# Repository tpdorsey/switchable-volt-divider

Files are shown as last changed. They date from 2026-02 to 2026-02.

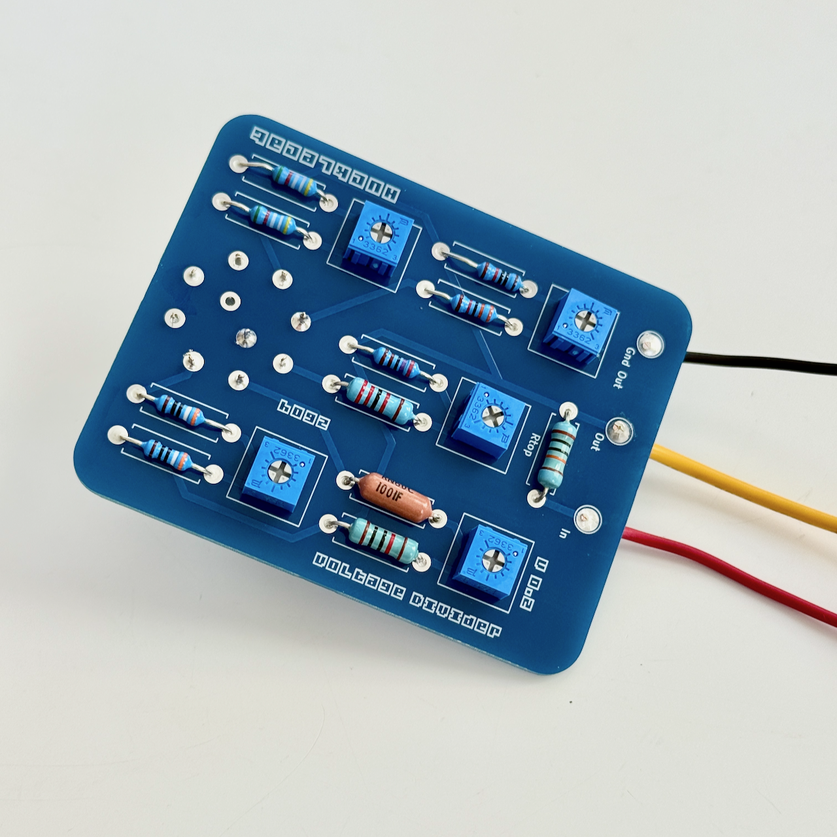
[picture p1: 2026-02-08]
docs/front.png

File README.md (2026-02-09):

# Switchable Voltage Divider PCB — Circuit Overview and Build Guide

This PCB implements a **switchable resistive voltage divider** intended to derive accurate, repeatable fractions of a stable DC reference (nominally 10 V). Each divider tap produces a fixed ratio of the input voltage, selectable via a 1-pole, 5-position rotary switch. 

The design is optimized for trimming resistance values to achieve (relatively) precise divider values.

![Hand-assembled blue PCB voltage divider board with five selectable divider networks. The board shows multiple precision metal film resistors, blue Bourns 3362 trim potentiometers, and a single film capacitor, arranged around labeled divider sections. Three wires exit the right side for input, output, and ground. The layout is clean and symmetric, intended for a switchable precision voltage divider.](docs/front.png)

## Circuit Description

There are five taps on the PCB. Each tap on the PCB has space for two resistors and a trim pot (Bourns 3362).

Each tap is a **two-resistance voltage divider**:

```
Vin ── Rtop ──┬── Vout
              |
            Rbottom
              |
             GND
```

**Rtop** is a fixed value for all taps. (I used 100k.)

**Rbottom** is implemented as:

* A fixed resistor
* A small trim potentiometer (Bourns 3362)
* Optional second series resistor or jumper

This arrangement allows:

* Coarse ratio setting with fixed resistors
* Fine trimming with a low-value trimmer
* Good long-term stability by minimizing the trimmer’s contribution to total resistance

The rotary switch selects which divider output is routed to the output jack.

### Divider Equation

The fundamental voltage divider relationship is:

```
Vout = Vin * (Rbottom / (Rtop + Rbottom))
```

To design a divider for a desired ratio:

```
k = Vout / Vin
```

Solve for the shunt resistor:

```
Rbottom = (k / (1 - k)) * Rtop
```

### Example Divider Values 

Exact values matter. Let's say Rtop = 100,468 Ω.

| Divider ratio | Vout (from 10V) | Rbottom (ideal) |
| ---- | --- | --- |
| 0.5 | 5.0 V | 100,468 Ω |
| 0.3 | 3.0 V | 43,058 Ω |
| 0.2 | 2.0 V | 25,120 Ω |
| 0.1 | 1.0 V | 11,163 Ω |
| 0.01 | 0.1 V | 1,015 Ω |

In practice, these are realized using nearby standard values plus the trim pot to dial in the exact ratio.

You can, of course, use whatever ratios you like.

## Build Notes

The PCB is designed around a 1-pole 5-position (using 1P/8-pos form factor) like the one available from pedal parts supplier [Love My Switches](https://lovemyswitches.com/mini-rotary-switch-1p5t-1-pole-5-position-knurled-shaft/) or [PedalPCB](https://www.pedalpcb.com/product/mini-rotary-switch-1p5t/).

The PCB is also designed to fit within a standard 125B aluminum enclosure with room to install your choice of inputs and outputs (banana jacks, RCA, etc.).

## Build Instructions (Summary)

1. **Populate fixed resistors first**

   * Use precision metal film resistors where possible.
   * Keep resistor types consistent across all taps to improve ratio tempco matching.

2. **Install the trimmer (Bourns 3362)**

   * Use the trimmer only for fine adjustment.
   * Aim to keep it near mid-range once trimmed.

3. **Install jumpers or series resistors**

   * If a second resistor footprint is unused, install a jumper.
   * Otherwise, use it to reduce the trim range and improve stability.

4. **Clean the PCB**

   * Thoroughly remove flux residue, especially around the 0.01 tap.
   * Leakage dominates errors at low-voltage, high-impedance nodes.

5. **Trim each divider**

   * Apply a stable input voltage.
   * Measure Vin and Vout with the same DMM.
   * Adjust the trimmer until the ratio (Vout / Vin) matches the target value.

6. **Final assembly**

   * Mount the PCB and switch in a metal enclosure.
   * Keep wiring short and thermally uniform.

### Notes on Use

* Divider accuracy should be evaluated **ratiometrically**, not as an absolute voltage.
* The 0.01 tap is most sensitive to leakage, temperature gradients, and contamination.
* A metal enclosure significantly improves short-term stability and repeatability.

This design is intentionally simple, adjustable, and reproducible.

## License

<a href="https://github.com/tpdorsey/switchable-volt-divider">Switchable Voltage Divider PCB</a> © 2026 by <a href="https://tpdorsey.com/">Terrence Dorsey</a> <p>is licensed under <a href="https://creativecommons.org/licenses/by-sa/4.0/">Creative Commons Attribution-ShareAlike 4.0 International</a><p>

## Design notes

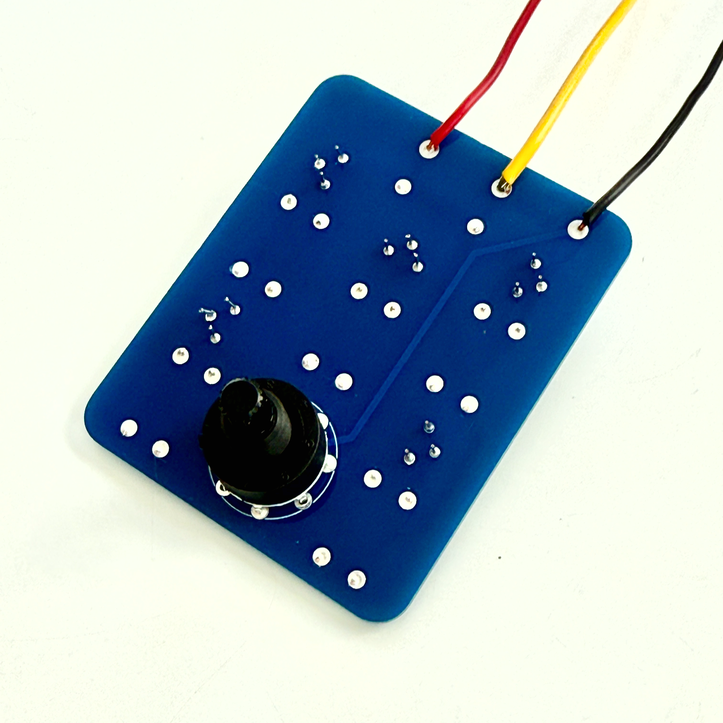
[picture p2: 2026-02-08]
docs/back.png

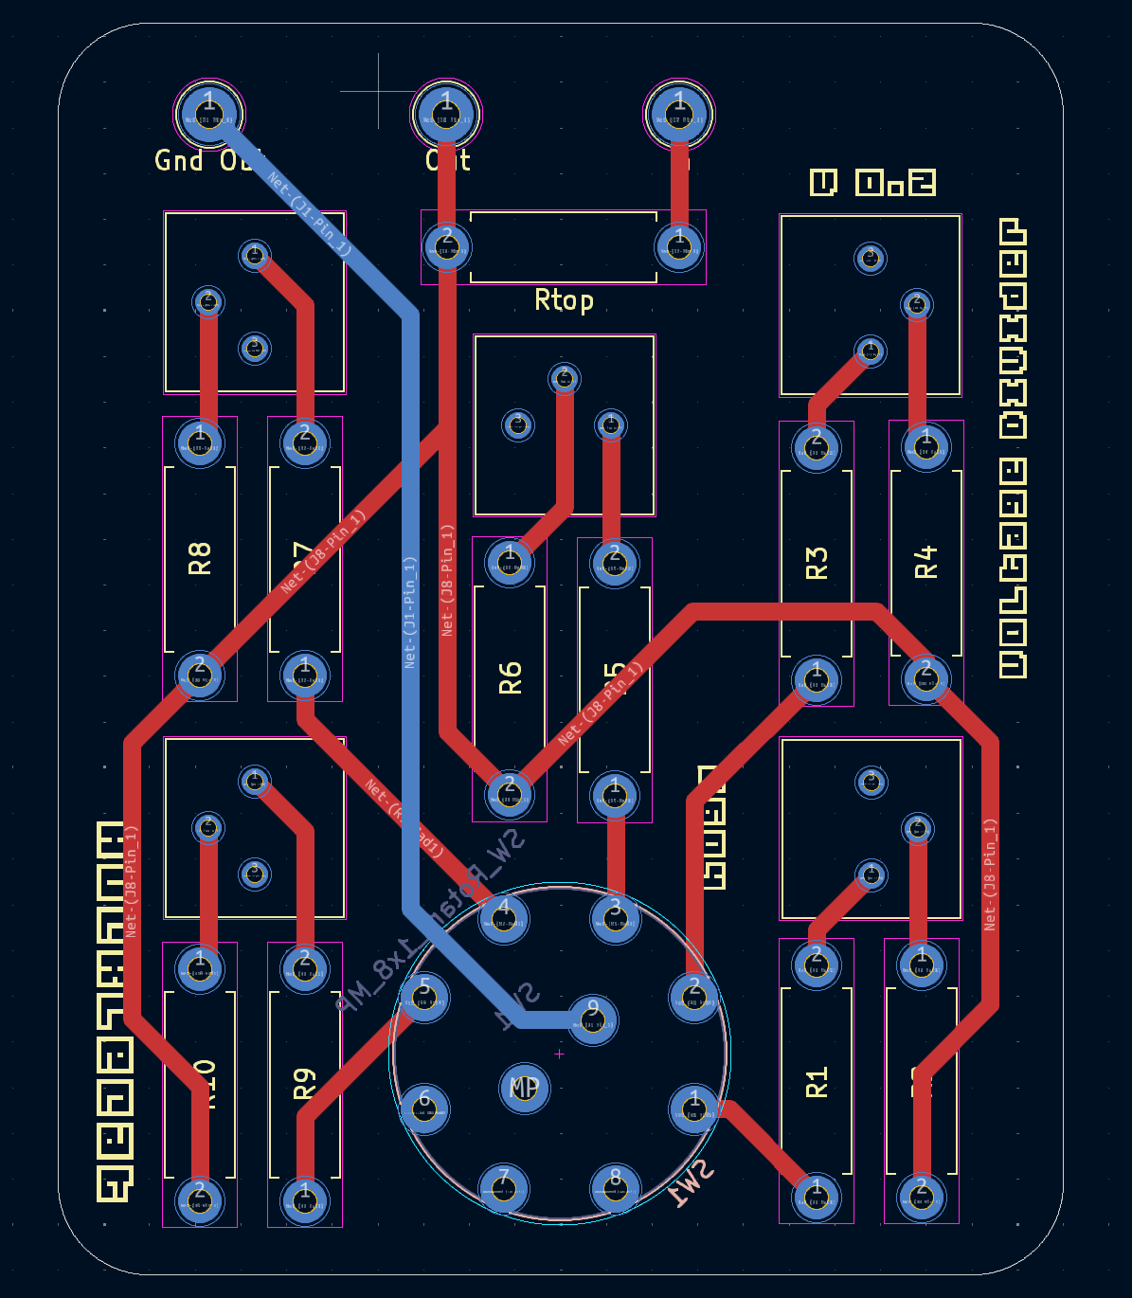
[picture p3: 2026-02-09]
docs/pcb.png

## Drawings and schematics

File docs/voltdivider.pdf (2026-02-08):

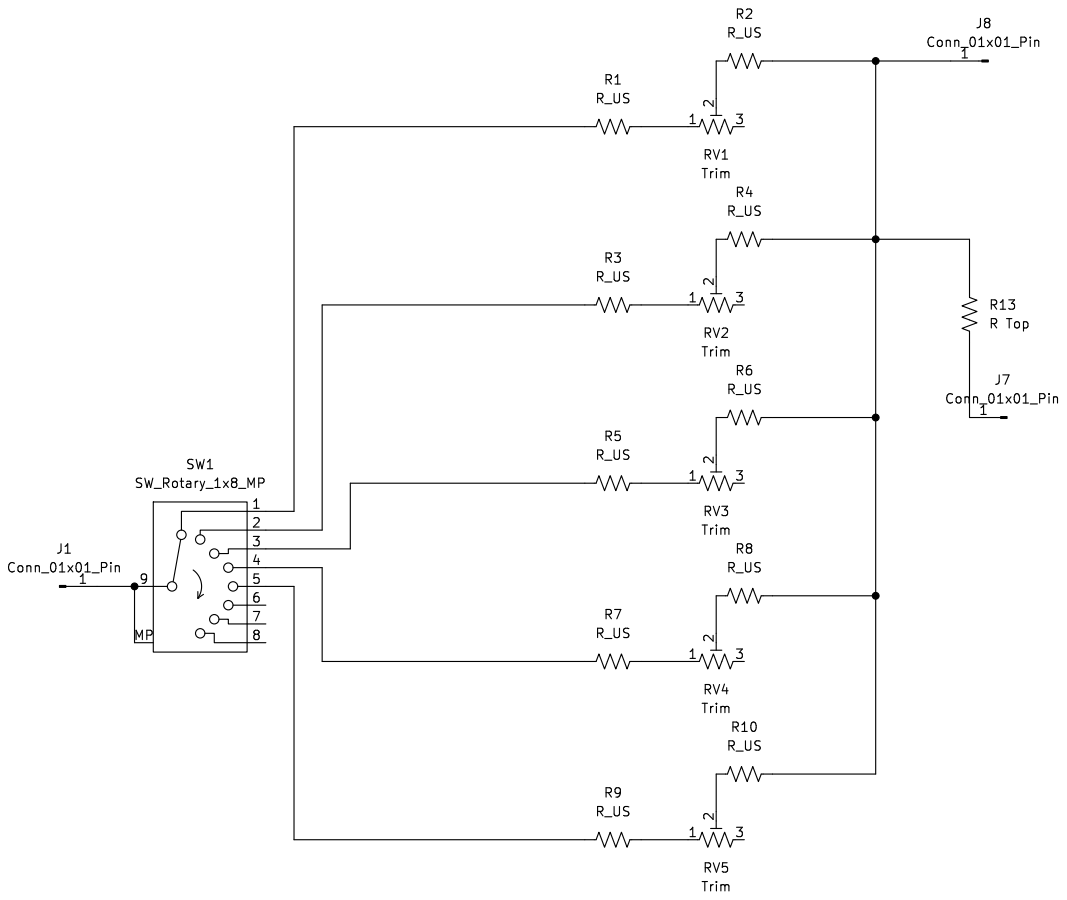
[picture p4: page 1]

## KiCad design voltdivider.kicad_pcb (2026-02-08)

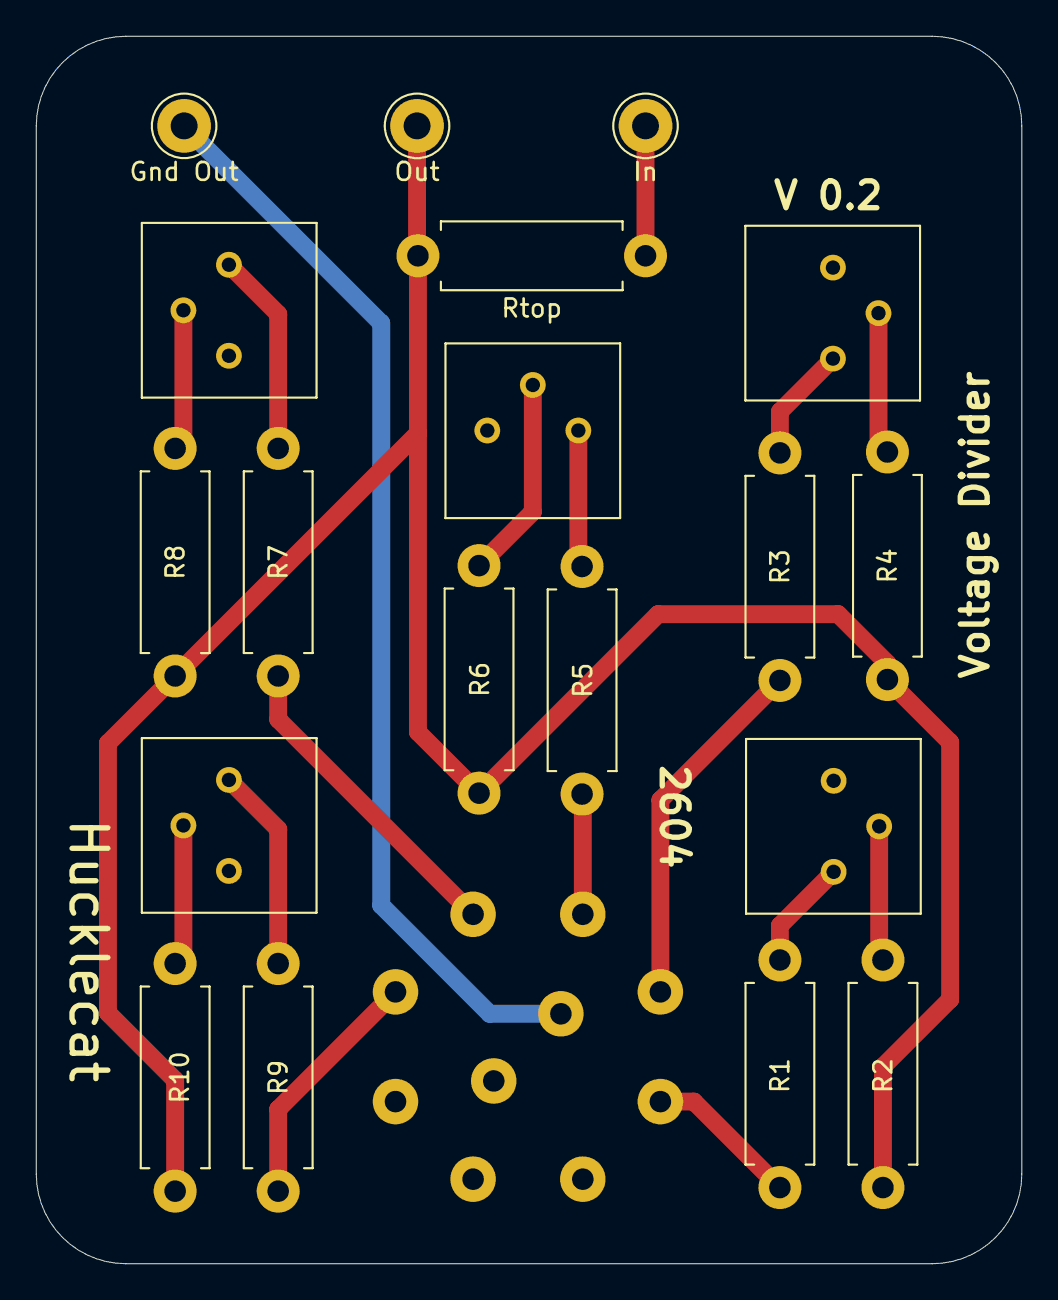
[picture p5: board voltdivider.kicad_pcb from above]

Board: 2 copper layers, 55.0 x 68.5 mm, 20 parts (1 on the bottom side), 18 nets.

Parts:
Gnd Out: Conn_01x01_Pin; Pin_D1.3mm_L11.0mm_LooseFit
In: Conn_01x01_Pin; Pin_D1.3mm_L11.0mm_LooseFit
Out: Conn_01x01_Pin; Pin_D1.3mm_L11.0mm_LooseFit
R1, R2, R3, R4, R5, R6, R7, R8, R9, R10: R_US; R_Axial_DIN0411_L9.9mm_D3.6mm_P12.70mm_Horizontal
RV1, RV2, RV3, RV4, RV5: Trim; Potentiometer_Bourns_3386P_Vertical
Rtop: R Top; R_Axial_DIN0411_L9.9mm_D3.6mm_P12.70mm_Horizontal
SW1: SW_Rotary_1x8_MP; Rotary_Switch_8

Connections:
unnamed: Gnd Out.1, SW1.9
unnamed: In.1, Rtop.1
unnamed: Out.1, R2.2, R4.2, R6.2, R8.2, R10.2, Rtop.2
unnamed: R1.1, SW1.1
unnamed: R1.2, RV1.1
unnamed: R2.1, RV1.2
unnamed: R3.1, SW1.2
unnamed: R3.2, RV2.1
unnamed: R4.1, RV2.2
unnamed: R5.1, SW1.3
unnamed: R5.2, RV3.1
unnamed: R6.1, RV3.2
unnamed: R7.1, SW1.4
unnamed: R7.2, RV4.1
unnamed: R8.1, RV4.2
unnamed: R9.1, SW1.5
unnamed: R9.2, RV5.1
unnamed: R10.1, RV5.2
